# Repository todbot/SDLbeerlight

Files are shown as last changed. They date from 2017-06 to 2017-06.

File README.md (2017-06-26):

# SDLbeerlight

An overly complicated light for announcing a certain time of day (or state of mind).  Created by 0x02 Design Lab Residents.

The Beer Light consists of:

- Arduino Uno running sketch in this repo
- Custom Arduino shield acting as breakout board for the following modules:
- An illuminated big button with integrated LED
- 24 WS2812 RGB LEDs
- Sure Electronics DE-DP14211 LED panel http://store3.sure-electronics.com/de-dp14211
- MP3 module with built-in 10W amp FN-BC04-TB -  https://electronics123.odoo.com/shop/product/fn-bc04-tb-4-buttons-triggered-mp3-player-board-with-10w-amplifier-and-terminal-blocks-8267 and two speakers
- LM2596 adjustable power supply module set to +5V output
- Custom-designed box and graphics by MotherFather Design

Dan, if you want to change things:
- The file "001.mp3" on the MP3 SD card is the sound that is played
- The trimpot on the MP3 board controls the sound volume
- The variable "msg" in the sketch sets the sign's default text message

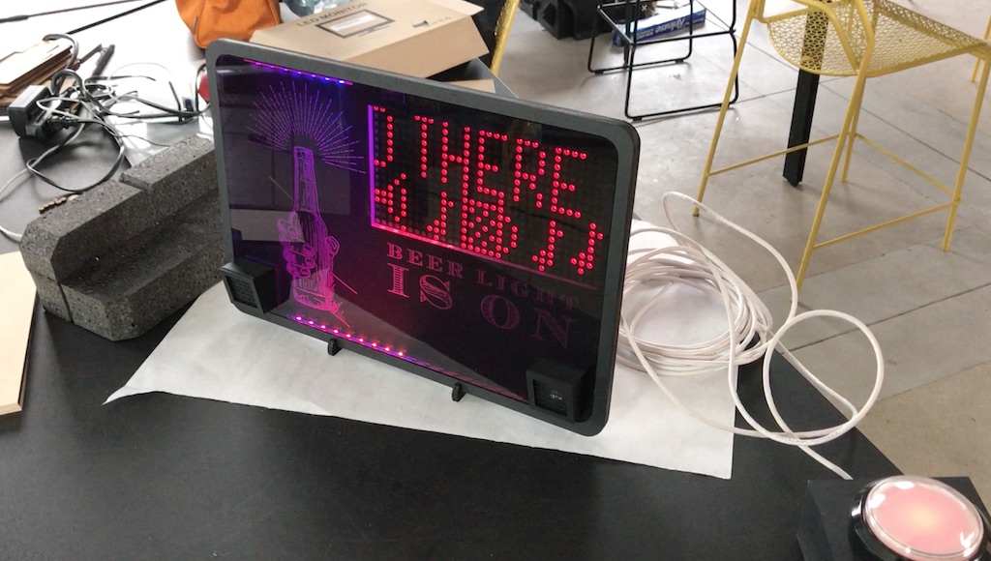
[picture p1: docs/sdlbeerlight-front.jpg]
front

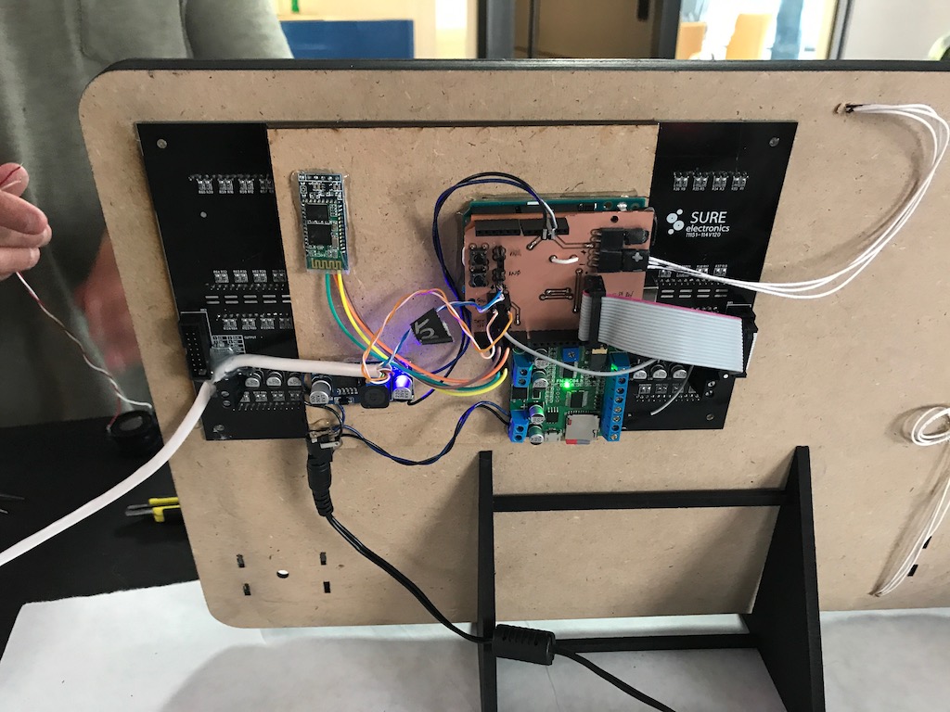
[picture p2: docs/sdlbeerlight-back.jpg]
back

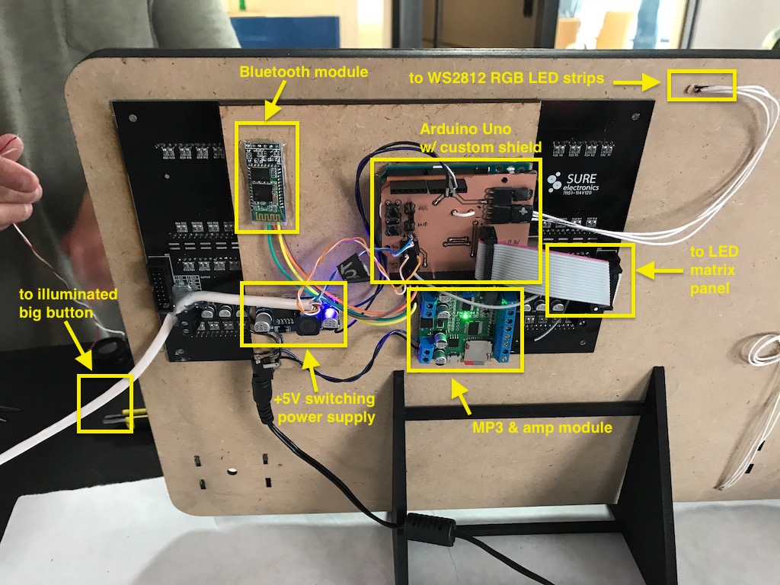
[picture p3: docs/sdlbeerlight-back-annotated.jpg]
back-annotated

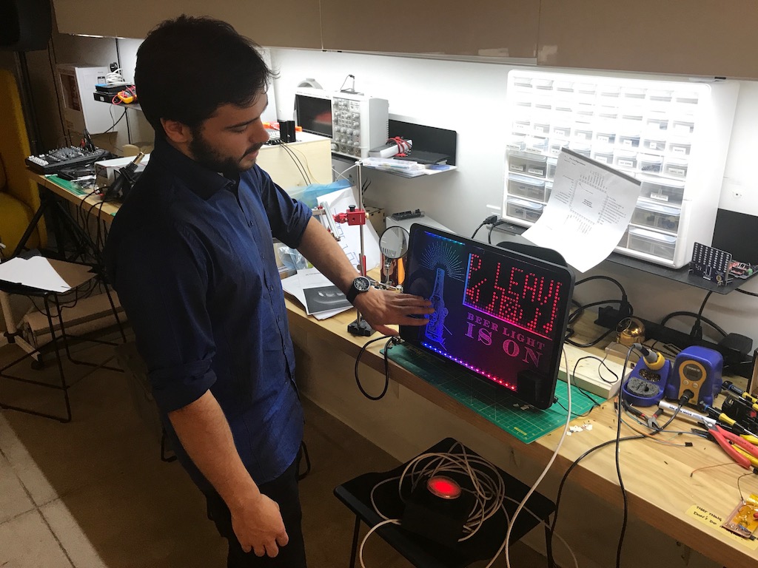
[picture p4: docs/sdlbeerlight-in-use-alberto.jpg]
inuse


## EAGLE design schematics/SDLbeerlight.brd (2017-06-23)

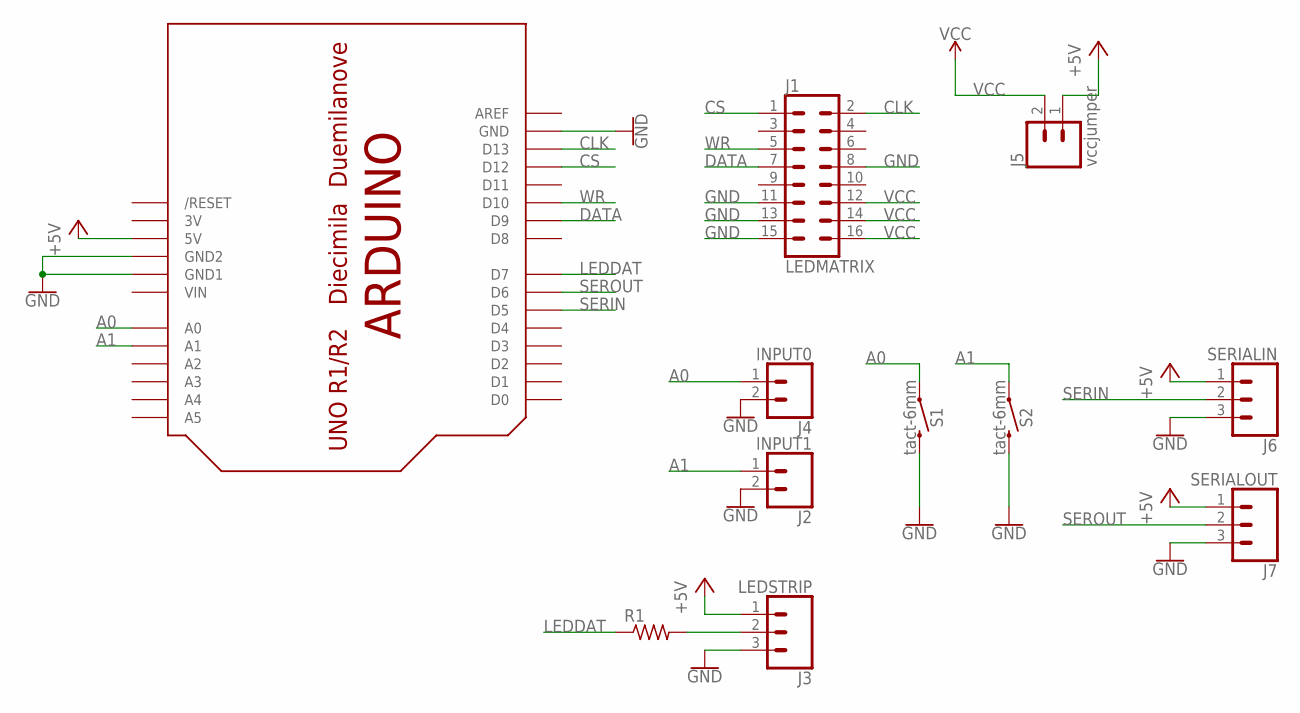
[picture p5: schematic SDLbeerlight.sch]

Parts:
J1: LEDMATRIX; 2X8
J2: INPUT1; 1X02_LONGPADS
J3: LEDSTRIP; 1X03_LONGPADS
J4: INPUT0; 1X02_LONGPADS
J5: vccjumper; 1X02_LOCK_LONGPADS
J6: SERIALIN; 1X03_LONGPADS
J7: SERIALOUT; 1X03_LONGPADS
R1: R-US_0204/7; 0204/7
S1, S2: tact-6mm; TACTILE_SWITCH_PTH_6.0MM
U$2: ARDUINOUNO; ARDUINO

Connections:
3V: U$2.3V
+5V: J3.1, J5.1, J6.1, J7.1, U$2.5V
A0: J4.1, S1.1, U$2.A0
A1: J2.1, S2.1, U$2.A1
CLK: J1.2, U$2.D13
CS: J1.1, U$2.D12
DATA: J1.7, U$2.D9
GND: J1.8, J1.11, J1.13, J1.15, J2.2, J3.3, J4.2, J6.3, J7.3, S1.3 (2), S2.3 (2), U$2.GND, U$2.GND1, U$2.GND2
LEDDAT: R1.1, U$2.D7
unnamed: J3.2, R1.2
SERIN: J6.2, U$2.D5
SEROUT: J7.2, U$2.D6
VCC: J1.12, J1.14, J1.16, J5.2
VIN: U$2.VIN
WR: J1.5, U$2.D10

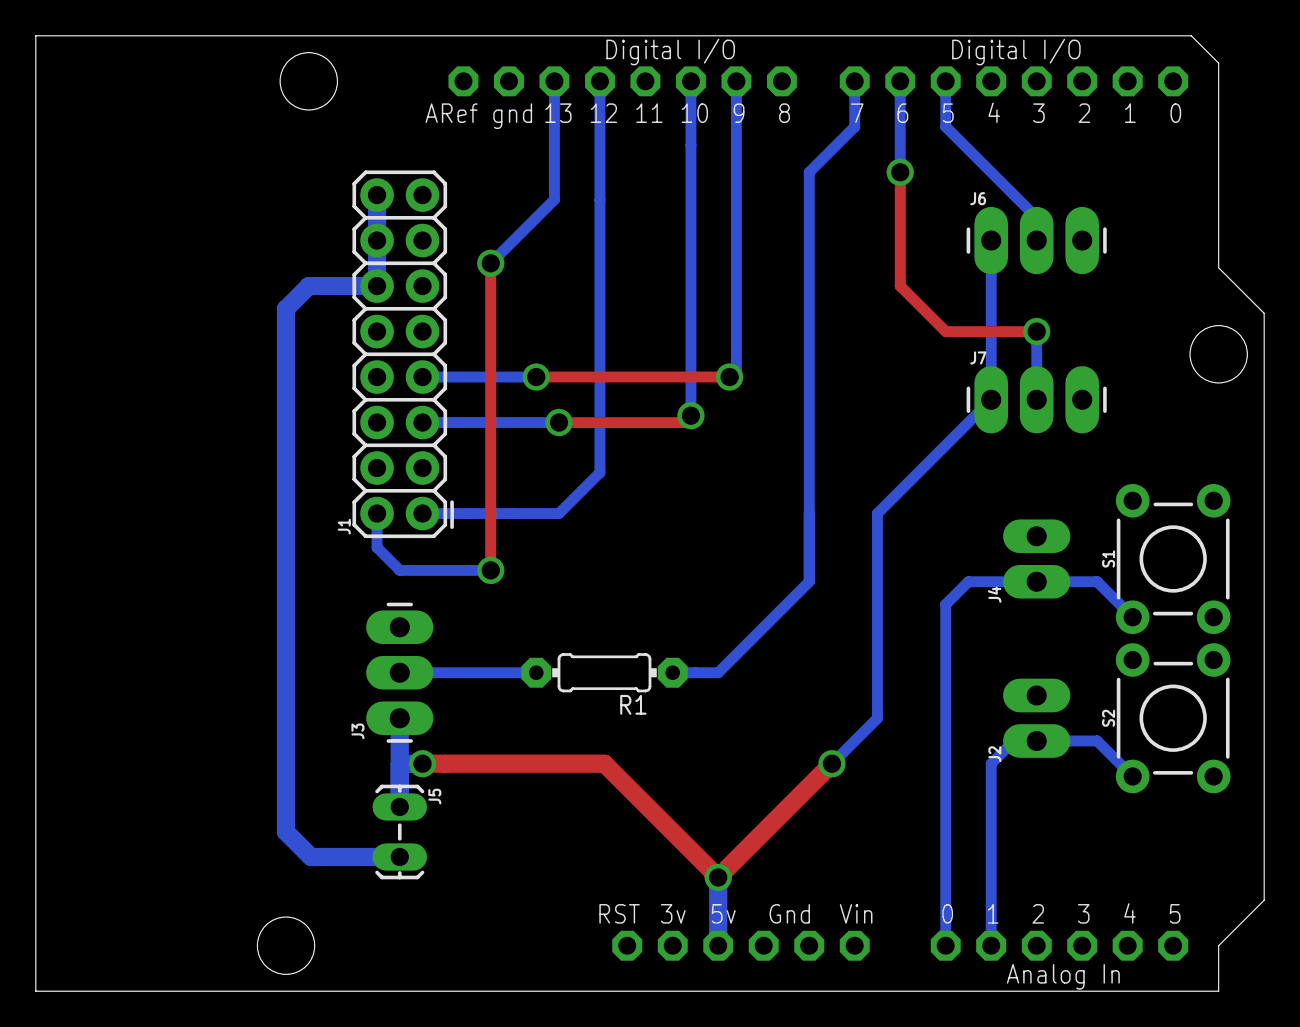
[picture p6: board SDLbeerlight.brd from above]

Board: 2 copper layers, 68.6 x 53.3 mm, 11 parts (0 on the bottom side), 13 nets.

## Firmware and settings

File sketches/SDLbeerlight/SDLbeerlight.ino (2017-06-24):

/**
 * SDLbeerlight -
 *
 * Uses bicolor LED panel: https://www.adafruit.com/product/3054
 *
 * This code copies from https://gist.github.com/ladyada/dbb4e736967dd918f140
 *
 * Uses libraries:
 * - HT1632 - https://github.com/gauravmm/HT1632-for-Arduino
 * - FastLED 3.1 - https://github.com/FastLED/FastLED
 * - Bounce2 - https://github.com/thomasfredericks/Bounce2
 *
 * Stupid bluetooth implementation by @otrebla333
 *
 * @todbot
 *
 */

#include <HT1632.h>
#include <font_5x4.h>
#include <font_8x4.h>
#include <images.h>
#include <SoftwareSerial.h>

#define FASTLED_INTERNAL
#define FASTLED_ALLOW_INTERRUPTS 1
#include <FastLED.h>
FASTLED_USING_NAMESPACE

#include <Bounce2.h>

int i = 0;

const int pinDisplayCLK = 13;
const int pinDisplayCS1 = 12;
const int pinDisplayCS2 = 12; // unused
const int pinDisplayWR  = 10;
const int pinDisplayDATA = 9;
const int pinLedStrip    = 7;
const int pinIn0 = A0;
const int pinIn1 = A1;
const int pinMP3 = 6;


#define NUM_LEDS 24
#define LED_BRIGHTNESS 200
#define FRAMES_PER_SECOND  60
CRGB leds[NUM_LEDS];
uint8_t gHue;

const byte IMG_BEER [] PROGMEM = { 0b11111111, 0b01101011, 0b01010101, 0b01101011, 0b01010101, 0b11111111, 0b00100010, 0b00011100};
#define IMG_BEER_WIDTH    8
#define IMG_BEER_HEIGHT   8

Bounce debouncer0 = Bounce();
Bounce debouncer1 = Bounce();

int mode = 0;
bool soundmode = false;
uint32_t soundDurationMillis = 5000;
uint32_t soundStartMillis;

const int msgMaxLen = 32;
//                       012345678901234567890123
char msg[ msgMaxLen ] = "time for beer";
int msgPos = 0;

#define BLUETOOTH_MAX_LENGTH 32   //Has to be 2 char more that expected max message length
                                  //@otrebla333: Should be the same than msgMaxLen?


// define this to use software serial, otherwise it will use hardware serial
#define BT_USE_SWSERIAL

#ifdef BT_USE_SWSERIAL
//Bluetooth software serial
SoftwareSerial bluetooth(2,3); // Arudino (RX,TX) - Bluetooth (TX,RX)
#endif

//String for storing data received from bluetooth
String rxDataBT;                //Received data
String messageDisplay;
//Char arrays for text processing
char messageDisplayChar[BLUETOOTH_MAX_LENGTH];

//BEER LIGHT GLOBAL STATUS VARIABLE; 0 = OFF
bool beerLight = 0;

//MP3 Player Software Serial
SoftwareSerial MP3(4,5);


void setup ()
{
    Serial.begin(115200);
    Serial.println(F("Hello from SDL light!"));

#ifdef BT_USE_SWSERIAL
    bluetooth.begin(57600);
    bluetooth.println("Hello");
#else
    // make hardware serial act like bluetooth software serial
    #define bluetooth Serial
#endif
    delay(500);

    pinMode(pinIn0, INPUT_PULLUP);
    pinMode(pinIn1, INPUT_PULLUP);
    pinMode(pinMP3, OUTPUT);
    debouncer0.attach(pinIn0);
    debouncer0.interval(50); // interval in ms
    debouncer1.attach(pinIn1);
    debouncer1.interval(50); // interval in ms

    HT1632.setCLK(pinDisplayCLK);
    HT1632.begin(pinDisplayCS1, pinDisplayCS2, pinDisplayWR, pinDisplayDATA);
    // HT1632.begin(DISPLAY_CS1, DISPLAY_CS2, DISPLAY_WR, DISPLAY_DATA);

    FastLED.addLeds<WS2812, pinLedStrip,GRB>(leds, NUM_LEDS);
    FastLED.setBrightness(LED_BRIGHTNESS);     // set master brightness control
}

void loop()
{
    doInputs();
    doPanel();
    doLedStrip();
    doSound();

    if(listenBluetooth())
    {
      analyzeMessage();
    }

}
//7E FF 06 03 00 00 01 EF

// turn on or off the beer light
void toggleLight()
{
    mode = !mode;
    if( mode ) {
        soundmode = true;
        soundStartMillis = millis();
    }
    else {
        soundmode = false;
    }
}

void doInputs()
{
    debouncer0.update();
    debouncer1.update();

    if( debouncer0.fell() ) {
        Serial.print(F("Button0: push! mode:")); Serial.println(mode);
        toggleLight();
    }

    if( debouncer1.fell() ) {
        Serial.print(F("Button1: push! mode:")); Serial.println(mode);
        toggleLight();
    }

}

void doLedStrip()
{
    EVERY_N_MILLISECONDS( 1000 / FRAMES_PER_SECOND ) {

        if( mode ) {
            rainbow();
        }
        else {
            fadeToBlackBy( leds, NUM_LEDS, 20);
        }

        // do some periodic updates
        EVERY_N_MILLISECONDS( 10 ) { gHue++; } // slowly cycle the "base color" through the rainbow

        // send the 'leds' array out to the actual LED strip
        FastLED.show();
    }

}

void doPanel()
{
    EVERY_N_MILLISECONDS( 200 ) { //200
        HT1632.renderTarget(0);
        HT1632.clear();          // Clear the previous image contents:

        if( mode ) {
            HT1632.drawText(msg, msgPos, 0, FONT_8X4, FONT_8X4_END, FONT_8X4_HEIGHT);
            //Serial.println(msgPos);
            msgPos--;
            //if( msgPos < -(msgMaxLen * 4) ) { msgPos = 0; } // 4 pixel wide font_end
            if( msgPos < -(messageLength() * 4) ) { msgPos = 32; } // 4 pixel wide font_end
            // if( msgPos < -msgMaxLen ) { msgPos = 0; }
            // Draw a different image based on the frame number:
            if(i++ % 2 == 0) {
                HT1632.selectChannel(0); // Select the first channel (green)
                HT1632.drawImage(IMG_SPEAKER_A, IMG_SPEAKER_WIDTH,  IMG_SPEAKER_HEIGHT, 0, 8);
                HT1632.drawImage(IMG_MUSICNOTE, IMG_MUSICNOTE_WIDTH,  IMG_MUSICNOTE_HEIGHT, 8, 8);
                // HT1632.drawImage(IMG_MUSIC, IMG_MUSIC_WIDTH,  IMG_MUSIC_HEIGHT, 13, 5);
                HT1632.drawImage(IMG_BEER, IMG_BEER_WIDTH,  IMG_BEER_HEIGHT, 13, 8);
                HT1632.drawImage(IMG_MUSICNOTE, IMG_MUSICNOTE_WIDTH,  IMG_MUSICNOTE_HEIGHT, 23, 8);
                HT1632.drawImage(IMG_MUSICNOTE, IMG_MUSICNOTE_WIDTH,  IMG_MUSICNOTE_HEIGHT, 28, 9);

                HT1632.selectChannel(1); // Select the first channel (green)
                HT1632.drawImage(IMG_BEER, IMG_BEER_WIDTH,  IMG_BEER_HEIGHT, 13, 8);

            } else {
                HT1632.selectChannel(1); // Select the second channel (red)
                HT1632.drawImage(IMG_SPEAKER_B, IMG_SPEAKER_WIDTH,  IMG_SPEAKER_HEIGHT, 0, 8);
                HT1632.drawImage(IMG_MUSICNOTE, IMG_MUSICNOTE_WIDTH,  IMG_MUSICNOTE_HEIGHT, 8, 9);
                HT1632.drawImage(IMG_BEER, IMG_BEER_WIDTH,  IMG_BEER_HEIGHT, 13, 8);
                // HT1632.drawImage(IMG_MUSIC, IMG_MUSIC_WIDTH,  IMG_MUSIC_HEIGHT, 13, 4);
                HT1632.drawImage(IMG_MUSICNOTE, IMG_MUSICNOTE_WIDTH,  IMG_MUSICNOTE_HEIGHT, 23, 9);
                HT1632.drawImage(IMG_MUSICNOTE, IMG_MUSICNOTE_WIDTH,  IMG_MUSICNOTE_HEIGHT, 28, 8);
            }
        }
        HT1632.render();
    }

}

void rainbow()
{
  // FastLED's built-in rainbow generator
  fill_rainbow( leds, NUM_LEDS, gHue, 7);
}

bool listenBluetooth()
{
    if( bluetooth.available()>1 ) //Aqui hay num de bytes disponibles up to 64 bytes
    {
      rxDataBT= bluetooth.readStringUntil('\0');

      if (rxDataBT.length()>BLUETOOTH_MAX_LENGTH)
      {
          bluetooth.println("Message too long, muy mal");
      }
      else
      {
        Serial.println(rxDataBT);
      }
      return true;
    }
    else return false;
}

void analyzeMessage()
{
    bool beer=0;
    bool on=0;
    bool off=0;
    bool please=0;
    bool badWords=0;
    bool text=0;
    bool play=0;
    bool message=0;

    message = lookForWords("text:");
    play= lookForWords("play");

    if (play)MP3.println(0x7E18);

    if(message)
    {
      messageDisplay=rxDataBT.substring(5);
      messageDisplay.toCharArray(msg,messageDisplay.length());
    }
    else
    {
        badWords = lookForWords("fuck,fucking,motherfucker,shit");
        beer=lookForWords("BEER,beer,Beer,cerveza,Cerveza,CERVEZA,light,LIGHT,Light");

        if(badWords)
            {
            bluetooth.println("Wow wow calm down, you are not ready for a beer");
            delay(1000);
            bluetooth.println("BEER LIGHT HAS BEEN DISABLED FOR 5 MINUTES");
            for (int i=0;i<20;i++) delay(1000); //delay 300 sec -> 5 min
            //THIS FOR COMPLETELY STOPS ALL OTHER FUNCTIONS
            bluetooth.println("TRY AGAIN");
            }

        else if(beer)
            {
                on = lookForWords("ON,on,On,encendida,go,GO,Go");
                off = lookForWords("OFF,off,Off,NO,no,No,down");

                if(on)
                {
                    please = lookForWords("PLEASE,please,Please,PORFAVOR,porfavor,Por favor,Por Favor, por favor, hijo de puta");
                    if(please)
                    {
                        bluetooth.println("Beerlight is ON!");
                        beerLight = 1;
                        toggleLight();
                    }
                    else bluetooth.println("That's not how you ask for beer :[");
                }

                else if (off)
                {
                    bluetooth.println("Beerlight is OFF :(");
                    beerLight = 0;
                    toggleLight();
                }

            }
    }
}


//Looks for a word or words (word1,word2,word3,wordN)in the received bluetooth message, returns true or false
bool lookForWords(String multipleWords)
{
  int currentIndex = 0;
  int commaIndex=0;
  String Word;

  //Looks for the first word given in the multipleWords String
  for (int i=0; i<=multipleWords.length();i++)
    {
    commaIndex=multipleWords.indexOf(",",currentIndex);
    if (commaIndex==0)
      {
        if(currentIndex==0)
          {
            Word=multipleWords;
            i=multipleWords.length();
          }
      }
    else
      {
        Word=multipleWords.substring(currentIndex,commaIndex); //If no comma, only 1 word
        currentIndex=commaIndex+1;
      }

    //Checks that BTlength is equal or longer than the word lenght (-2 added for compensation of real length)
    if(rxDataBT.length()-2>=Word.length())
      {
      //If so, looks for the word in the string
      for (int i=0; i<=rxDataBT.length() - Word.length();i++)
        {
          if(rxDataBT.substring(i,Word.length()+i) == Word) return true;
        }
      }
    }
  return false;


}

int messageLength()
{
  int i=0;
  while(msg[i]!='\0')
  {
    i++;
  }
  return i;
}

void doSound()
{
    // if( soundmode ) {
        if( (millis() - soundStartMillis) > soundDurationMillis ) {
            soundmode = false;
        }
    // }
    digitalWrite(pinMP3,!soundmode);
}

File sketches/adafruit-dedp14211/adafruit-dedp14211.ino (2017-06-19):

// Uses library https://github.com/gauravmm/HT1632-for-Arduino

#include <HT1632.h>
#include <font_5x4.h>
#include <images.h>

int i = 0;

#define DISPLAY_CLK  13
#define DISPLAY_CS1  12     // first panel's CS pin
#define DISPLAY_CS2  7      // second panel's CS pin
#define DISPLAY_WR   10
#define DISPLAY_DATA 9

const byte IMG_BEER [] PROGMEM = { 0b11111111, 0b01101011, 0b01010101, 0b01101011, 0b01010101, 0b11111111, 0b00100010, 0b00011100};
#define IMG_BEER_WIDTH 	 8
#define IMG_BEER_HEIGHT 	 8

void setup () {
  HT1632.setCLK(DISPLAY_CLK);
  HT1632.begin(DISPLAY_CS1, DISPLAY_CS2, DISPLAY_WR, DISPLAY_DATA);
}

void loop () {
  // Clear the previous image contents:
  HT1632.renderTarget(0);
  HT1632.clear();

  // Draw a different image based on the frame number:
  if(i++ % 2 == 0) {
    HT1632.selectChannel(0); // Select the first channel
    HT1632.drawImage(IMG_SPEAKER_A, IMG_SPEAKER_WIDTH,  IMG_SPEAKER_HEIGHT, 0, 4);
    HT1632.drawImage(IMG_MUSICNOTE, IMG_MUSICNOTE_WIDTH,  IMG_MUSICNOTE_HEIGHT, 8, 4);
    // HT1632.drawImage(IMG_MUSIC, IMG_MUSIC_WIDTH,  IMG_MUSIC_HEIGHT, 13, 5);
    HT1632.drawImage(IMG_BEER, IMG_BEER_WIDTH,  IMG_BEER_HEIGHT, 13, 5);
    HT1632.drawImage(IMG_MUSICNOTE, IMG_MUSICNOTE_WIDTH,  IMG_MUSICNOTE_HEIGHT, 23, 4);
    HT1632.drawImage(IMG_MUSICNOTE, IMG_MUSICNOTE_WIDTH,  IMG_MUSICNOTE_HEIGHT, 28, 5);
  } else {
    HT1632.selectChannel(1); // Select the second channel
    HT1632.drawImage(IMG_SPEAKER_B, IMG_SPEAKER_WIDTH,  IMG_SPEAKER_HEIGHT, 0, 4);
    HT1632.drawImage(IMG_MUSICNOTE, IMG_MUSICNOTE_WIDTH,  IMG_MUSICNOTE_HEIGHT, 8, 5);
    HT1632.drawImage(IMG_BEER, IMG_BEER_WIDTH,  IMG_BEER_HEIGHT, 13, 4);
    // HT1632.drawImage(IMG_MUSIC, IMG_MUSIC_WIDTH,  IMG_MUSIC_HEIGHT, 13, 4);
    HT1632.drawImage(IMG_MUSICNOTE, IMG_MUSICNOTE_WIDTH,  IMG_MUSICNOTE_HEIGHT, 23, 5);
    HT1632.drawImage(IMG_MUSICNOTE, IMG_MUSICNOTE_WIDTH,  IMG_MUSICNOTE_HEIGHT, 28, 4);
  }
  HT1632.render();

/*
  HT1632.renderTarget(0);
  HT1632.clear();
  if (~i & 0b01) { // On frames 1 and 3:
    HT1632.selectChannel(0); // Select the first channel
    // Draw a heart:
    HT1632.drawImage(IMG_HEART, IMG_HEART_WIDTH,  IMG_HEART_HEIGHT, 19, 1);
  }

  if (~i & 0b10) { // On frames 2 and 3:
    HT1632.selectChannel(1); // Select the second channel
    // Draw a heart:
    HT1632.drawImage(IMG_HEART, IMG_HEART_WIDTH,  IMG_HEART_HEIGHT, 19, 1);
  }

  HT1632.drawText("Ada", 2, 2, FONT_5X4, FONT_5X4_END, FONT_5X4_HEIGHT);
  HT1632.drawText("fruit !", 2, 9, FONT_5X4, FONT_5X4_END, FONT_5X4_HEIGHT);

  // Perform the drawing:
  HT1632.render();
*/
  delay(200);
}

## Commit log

2017-06-22 code actually does something useful now
    [SDLbeeright.brd]
2017-06-23 small update, and doc about libraries
    [SDLbeerlight.brd]
2017-06-23 fixed bluetooth dropping chars issue (sorta) because of fastled being called too often
    [SDLbeerlight.ino]
2017-06-24 fix firmware so sound turns off
    [SDLbeerlight.ino]
2017-06-27 SDLbeerlight Design Files
    Adobe Illustrator files you can use to cut out your own Beerlight!

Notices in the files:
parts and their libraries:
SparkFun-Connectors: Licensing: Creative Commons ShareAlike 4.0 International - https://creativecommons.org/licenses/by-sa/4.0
